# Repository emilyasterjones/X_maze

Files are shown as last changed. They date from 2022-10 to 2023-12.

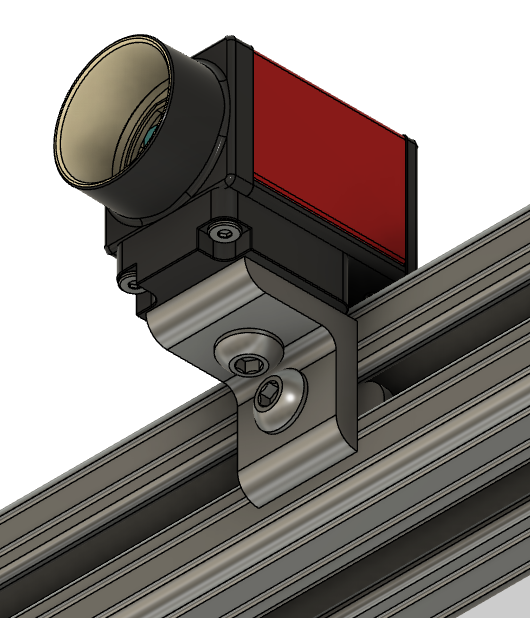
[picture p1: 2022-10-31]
Build/Camera_mount.png

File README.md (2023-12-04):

# X_maze
Build files and scripts for an automated delayed (non)match to direction task, with simultaneous video recording and TTL pulses to synchronize to additional data streams

This task is derived from the H maze, originally published in [(Seigle & Wilson, 2014)](https://elifesciences.org/articles/03061) with a detailed protocol published in [(Wirtshafter, Quan, & Wilson, 2021)](https://bio-protocol.org/e3947).

### GigE Allied Vision Camera Acquisition Instructions
1. Configure Ethernet Card
	1. Configure ethernet card according to [these settings](https://www.alliedvision.com/fileadmin/content/documents/products/cameras/various/installation-manual/GigE_Installation_Manual.pdf)
	1. [Turn off unnecessary protocols](https://www.mathworks.com/help/supportpkg/gigevisionhardware/ug/configure-gigabit-ethernet-network-adapter-on-windows.html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)
	1. [Set the camera's network to private](https://supportcenter.pleora.com/s/article/Correcting-Firewall-Issues-with-Third-Party-GigE-Vision-Devices-KBase)
1. Install OpenCV and Vimba SDK for Python
	1. `pip install opencv-python`
	1. Vimba => modify => select Vimba Python
	1. `pip install "C:/Program Files/Allied Vision/Vimba_X.X/VimbaPython/Source"` where x is whatever your version is
	
### FLIR Blackfly S USB3 Camera Acquisition Instructions
1. Install [SpinView](https://www.flir.com/products/spinnaker-sdk) to set camera settings and stream and record video. See camera_settings file for an example of streaming high resolution color video in dim lighting.
2. Read the [Blackfly S Manual](https://www.eureca.de/files/pdf/optoelectronics/flir/BFS-Installation-Guide.pdf).
3. To set up PySpinCapture to record using the GPU by installing the following:
* [Visual Studio (2022)](https://visualstudio.microsoft.com/)
* [CUDA Toolkit 12.2](https://developer.nvidia.com/cuda-downloads)
* [NVIDIA Video Codec SDK (12.1)](https://developer.nvidia.com/nvidia-video-codec-sdk/download)
* [Python (3.8)](https://www.python.org/downloads/)
* [Python Spinnaker SDK for your Python version](https://www.flir.com/support-center/iis/machine-vision/downloads/spinnaker-sdk-download/spinnaker-sdk--download-files/)
* [FFmpeg (6.0)](https://ffmpeg.org/download.html)
4. Set up Conda environment:
```
conda create -n flir python=3.8
pip install skikit-video
```

5. Update folders and constants in capture_video_FLIR.py, then run:
`python capture_video_FLIR.py name_of_output_video_file_stem` to capture video.

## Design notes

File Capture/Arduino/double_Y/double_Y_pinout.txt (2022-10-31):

Pin	Type	Loc
0	NA	NA
1	NA	NA
2	IR	TopLeft
3	IR	BottomLeft
4	IR	TopRight
5	Door	TopLeft
6	Door	BottomLeft
7	IR	BottomRight
8	Solenoid	TopLeft
9	Solenoid	BottomLeft
10	Door	TopRight
11	Door	BottomRight
12	Solenoid	TopRight
13	Solenoid	BottomRight
A0	TTL	NA
A1	NA	NA
A2	NA	NA
A3	NA	NA
A4	NA	NA
A5	NA	NA

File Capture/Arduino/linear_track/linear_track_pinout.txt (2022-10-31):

Pin	Type	Loc
0	NA	NA
1	NA	NA
2	IR	Left
3	IR	Right
4	NA	NA
5	NA	NA
6	NA	NA
7	NA	NA
8	Solenoid	Left
9	Solenoid	Right
10	NA	NA
11	NA	NA
12	NA	NA
13	NA	NA
A0	TTL	NA
A1	NA	NA
A2	NA	NA
A3	NA	NA
A4	NA	NA
A5	NA	NA

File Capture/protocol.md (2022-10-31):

## Overarching Protocol
### Housing
#### General
* Reverse light/dark cycle, ideally 1-2 weeks before pre-op training. 
* Add wheel to encourage running and wood block since chewing is reduced on food dep.

#### Food restriction
**Pre-op, on day....**
* 0. Remove hopper, change cage, add restriction card.
* 0-2. 1.5g/mouse plus a weigh boat with soy milk.
* 3+. Adjust by weight.

1 day before surgery, single house without wheel. Return to free feeding, staying with food on the floor. Add gel food & water (for easy access during recovery), sprinkles (to encourage foraging), and nestlet (for heat support).

**Post-op, on day....**
* 0-3. Ad lib food.
* 4-5. 2g/mouse plus soy milk.
* 6+. Adjust by weight. Note that mice remain underweight for some time postop, so don't go below their pre-op baseline (weight of implant = 4g ~= 15% of a 25g mouse's weight)

### Training order
**Pre-op, on day.....**
* 0. Set up cage and begin food restriction. Label tails with sharpies.
* 1 & 2. Open field (OF) for 30 minutes with running wheel and lots of toys. Handle mice.
* 3+. Linear track (LT) for 20-30 minutes. Start at 25uL reward, lowering gradually to 10uL over days so mice on average get <1.5mL during tracks runs so they don't get sated.
* n+. Once mice reach 2 trials/min for 2 days, X-maze double-forced for 20-30 minutes, with same reward progression. Continue until 4 trials/min for 2 days. Optional: switch to X-maze probe, continuing until 75% correct for 2 days. Can run 2 sessions per day to speed up learning if needed.

**Post-op, on day....**
* 1-3. Record 10-20 min in OF. 
* 4+. Record HC => LT => HC => OF, 20 minutes each, until 4 trial/min or 3 days, whichever comes last. Make each recording epoch a separate trigger on the SpikeGLX file. 10uL reward for all tracks.
* n+. Substitute LT for X-maze probe. Continue until until 75% correct or 10 days, then switch to X-maze reversal, also continuing until 75% correct or 10 days.

## Daily protocol
### Set up
#### Behavior
1. Fill syringe with milk. Release valve, let descend to poke, then close again.
1. Thread tubing into solenoid. Clean poke. Open syringe valve. Fill syringe to target volume.
1. Switch on track hardware.
1. Do a test run to make sure the hardware functions are nominal. Swap out any nonfunctional components.
1. Dim lights to 5 lux. Close curtains and door.
1. Open camera in Vimba to confirm network adapter is still running. Restart computer if it isn't.
1. Remove yesterday's SpikeGLX sessions from the local drive

### Recording
#### Between animals
1. **PuTTy**: load "Arduino" settings. Under "Logging", enter the file name & location.
1. **Spyder**: set filename.
1. Wipe down the track and wheel. Reload the syringes to 5mL.
1. Weigh the next animal.

#### SpikeGLX
1. Plug in mouse: headfix with 1 screw, remove tape, release flex cable from slot, put headstage holder into slot, re-attach tape, plug flex cable into headstage, turn on LEDs.
1. Start acquisition and examine for abnormalities. Set filename.
1. Put mouse on the track next to and facing first poke.
1. Press "Enable Recording".

#### Behavior
1. Press "Open" to restart the Arduino and save all the output to the designated file. _Note: you can't have more than 1 program using the same port at once, so you can't have the Arduino IDE and PuTTy open at the same time._
1. Confirm TTL pulses appear on SpikeGLX.

#### Camera
1. Start the camera.
1. Confirm TTL pulses appear on SpikeGLX.

#### End Epoch
1. Stop video, then behavior, then recording.

#### End Session
1. Stop acquisition.
1. Put mouse back on the ball and unplug. Retape the flex slot.
1. Untwist the data cable.

### Clean up
1. Feed the mice.
1. Switch off power to track hardware. _Note: leaving solenoids plugged in for too long can cause them to fry._
1. Release tubing from solenoid. Drain milk, then rinse with water. Pump air through with plunger to dry.
1. Wipe everything again.
1. _Once a week_: Fill with ethanol/bleach and close valve. Let sit overnight.

### Troubleshooting
* **Arduino**: Check that power strip and switches are turned on and syringe valves are open. Confirm you are on the correct port and that you switched all the wiring and tubing between tasks correctly. Check that all wiring is securely connected. Try adding debug statements to the code in Arduino IDE, uploading it, and testing the task manually.
* **SpikeGLX**: If probe fails, clean the gold pins with IPA and try again.

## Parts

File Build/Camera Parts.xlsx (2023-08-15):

Build | Part | Short Name | Vendor | Cat # | Quantity | Price | Subtotal
Allied Vision - Mako G (capture_video.py) | AVT-GK-158C-POE Camera, GigE PoE, Sony IMX273; 1/2.9" CMOS; C-Mount; color; 1456x1088; 75.3fps; 12-bit ADC; IRC filter | GigE C-mount 75fps camera | 1st Vision | AVT-GK-158C-POE | 1 | 520 | 520
 | Cable, Hirose-8-pin to flying leads, 10m | Hirose 8-pin to bare ends cable | 1st Vision | CB-HIR8-I/O-10M | 1 | 150 | 150
 | Cable, CAT6 ethernet RJ45, screw locks, industrial grade, 10m | Ethernet cable | 1st Vision | CB-ALY-G-C6-SL-10M | 1 | 95 | 95
 | Lens, Kowa 6mm C Mount 2/3” C-mount | C-mount 6mm lens | 1st Vision | KOW-LM6JC | 1 | 130 | 130
 | Vostro 3681 Small Desktop | Computer | Dell | cav3681w10ps5095 | 1 | 749 | 749
 | Gigabit CT PCIe Desktop Adapter | Ethernet adapter | Dell | a2290104 | 1 | 42.99 | 42.99
 | 5.9" (149.86mm) BNC, Female Socket (Jack) To Wire Lead Test Lead 500VAC | BNC to bare ends | Digikey | 501-1030-ND | 1 | 10.29 | 10.29
 | AC to DC Power Supply Wall Adapter Transformer Single Output 12 Volt 1 Amp 12 Watt | Low noise power supply | Jameco | 170245 | 1 | 14.95 | 14.95
FLIR - Blackfly (pySpin) | Blackfly USB3 23S3C-C 2.3MP, Sony IMX392, 1/2.3" CMOS, C-mount, color, 1920x1200, 163fps, 12-bit ADC | USB C-mount 163fps camera | FLIR | BFS-U3-23S3C-C | 1 | 421 | 421
 | 6 pins, 4.5m GPIO Cable, Hirose HR10 Circular Connector | Hirose 6-pin to bare ends cable | FLIR | ACC-01-3010 | 1 | 43.9 | 43.9
 | USB 3.1, 5m, Type-A to Micro-B (Locking) Cable | USB cable | FLIR | ACC-01-2301 | 1 | 37.5 | 37.5
 | Fujinon DF6HA-1B, 6mm, 1/2", C mount Lens | C-mount 6mm lens | FLIR | LENS-15F3-60C | 1 | 238 | 238
 | 26.9mm by 17.9mm, 1/4"-20 Tripod Adapter | Tripod adapter | FLIR | ACC-01-0003 | 1 | 11.8 | 11.8
 | Alienware Aurora R16: i7-13700F, NVIDIA GeForce RTX 4070, 32GB DDR5 5600 MT/s, 1TB SSD | Computer | Dell |  | 1 | 1899 | 1899
 | 5.9" (149.86mm) BNC, Female Socket (Jack) To Wire Lead Test Lead 500VAC | BNC to bare ends | Digikey | 501-1030-ND | 1 | 10.29 | 10.29

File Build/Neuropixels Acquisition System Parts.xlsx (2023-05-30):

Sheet: Parts List
Part | Vendor | Catalog # | Cost in Euros | Cost in Dollars | Notes
Headstage | IMEC | HS_1000 | 250 | 300 | Buy backups in case of failure
PXIe Acquisition Module | IMEC | PXIe_1000 | 2400 | 2880 | IMEC PXIe module
Interface Cable | IMEC | CBL_1000 | 175 | 210 | Buy backups in case of failure
Coaxial Cable, SMA Male to BNC Male | Thorlabs | CA2848 |  | 19.37 | connects IMEC module to the BNC board
NI PXIe-1071, 4-Slot 3U PXI Express Chassis | National Instruments | 781368-01 |  | 1274 | Chassis
APS-4100 Auxiliary Power Source for NI DC Power Supplies | National Instruments | 779671-01 |  | 276 | Chassis power (optional)
Power Cord, AC, U.S., 120 VAC, 2.3 meters | National Instruments | 763000-01 |  | 13 | Chassis power
PXIe-6341, X Series DAQ | National Instruments | 781052-01 |  | 1404 | NI DAQ PXIe module; 24 DIO but only 8 at 1MHz
BNC-2110 Noise Rejecting, Shielded BNC Connector Block | National Instruments | 777643-01 |  | 446 | Sync block
SHC68-68-EPM Shielded Cable, 68 D-Typeto 68 VHDCI Offset, 0.5m | National Instruments | 192061-0R5 |  | 132 | Connects DAQ to sync block
NI PCIe-8381, x8 Gen2 MXI-Express for PXI Express Interface | National Instruments | 782361-01 |  | 1552 | Remote control PXIe module
NI PXIe-8381, x8 Gen2 MXI-Express for PXI Express Interface | National Instruments | 782362-01 |  | 1552 | Remote control PC module
MXI-Express Cable, Gen 2 x8, Copper, 5m | National Instruments | 782317-05 |  | 428 | Cable between RC modules
BNC Terminator, 10-Pack RFAdapter 50 Ohm RF Coax Adapter Connector Coaxial Cable End | Amazon | B07WPR8L6B |  | 9.99 | Prevents TTLs from carrying over into empty channels
Tripp Lite 12-outlet surge protector | Home Depot | TLP1208TELTV |  | 43.59 | Prevent hard drive failure due to power surge or outage
PC (see next tab) |  |  |  | 4000
Monitor |  |  |  | 250
Alternatives:
NI PCIe-8381, NI-PXIe-8381, MXI-Express Cable Bundle | NI | 782522-01 |  | 2975 | Bundle for the PCIe/PXIe and cable
PXIe -6363, X Series | NI | 781056-01 |  | 2691 | alternative to the 6341. NI DAQ PXIe module; 48 DIO, 32 at 1MHz
SCB-68A | NI | 782536-01 |  | 385 | alternative to the bnc board.
MXI-Express Cable, Gen 2 x8, Copper, 3m | National Instruments | 782317-03 |  | 286 | alternative/shorter mxi cable. this is the one included in the bundle above
Probes:
NPX 1.0 Probes w Cap (Box 5) | IMEC | PRB_1_4_0480_1_C | 6000 | 7200
Dummy NPX 1.0 Probes w Cap (Box 6) | IMEC | DPRB_1_4_0480_1_C | 900 | 1080

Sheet: Computer Specs
Minimum for Neuropixels: PCle chassis, minimum processing power, SSD, 1TB storage
Part | Type | Notes
Chassis | Precision 5820 Tower XCTO Base, 950W, PCle FlexBay RTX Chassis | PCle chassis required
Processor | Intel Xeon W-2133, DDR4-2666 | Intel processor required
Video card | Nvidea Quadro RTX4000, 8GB, 3DP, VirtualLink (XX20T)
Memory | 64GB DDR4 2666MHz | Required for processor
Boot drive | Intel NVMe PCle SSD
Storage drive controllers | RST-e with 1-2 Front FlexBay NVMe PCle Drives
Storage drive | M.2 1TB PCle NVMe Class 40 SSD | SpikeGLX records 75GB/probe/hour, so adjust according to your expected daily recording output

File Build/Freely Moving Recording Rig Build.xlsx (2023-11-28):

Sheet: Tap Plastics (enclosures)
Enclosure | Part | Quantity | Material | Height (in) | Width (in)
Rest Box | Floor | 1 | 1/8" P95 matte black acrylic | 6 | 6
Rest Box | Walls | 4 | 1/8" P95 matte black acrylic | 12 | 5 & 7/8
75cm OF | Floor | 1 | 1/4" P95 matte black acrylic | 30 | 30
75cm OF | Walls | 4 | 1/4" P95 matte black acrylic | 12 | 29 & 7/8
1.5m LT | Floor | 1 | 1/4" P95 matte black acrylic | 60 | 4
1.5m LT | Side Walls | 2 | 1/4" P95 matte black acrylic | 8 | 60
DY | Arm Walls | 8 | 1/4" P95 matte black acrylic | 8 | 20
DY | Hall Walls | 2 | 1/4" P95 matte black acrylic | 8 | 8 & 5/8
DY | Doors | 4 | 1/8" P95 matte black acrylic | 7 3/4 | 3 & 1/2
DY | Rudders | 8 | 1/2" P95 matte black acrylic | 2021-03-08 | 2
All |  | 1 | Caulking Gun
All |  | 1 | Sil-Pruf 10.1Oz Black
All |  | 1 | Weld-On 3 Cement (4 oz.)
All |  | 1 | Small BD-25/2 Hypo Applicator
All |  | 1 | Polypropylene Funnels
 |  |  | 1.4

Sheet: 8020.net (frame)
Part | Length (in) | Quantity | Cat # | Price | Subtotal
1.50” X 1.50” Ultra-LiteT-Slotted Profile - Four Open T-Slots | 65 | 8 | 1515-UL | 30.06 | 240.48
1.50” X 1.50” Ultra-LiteT-Slotted Profile - Four Open T-Slots | 90 | 4 | 1515-UL | 40.81 | 163.24
1.50” X 1.50” Ultra-LiteT-Slotted Profile - Four Open T-Slots | 15.25 | 12 | 1515-UL | 8.67 | 104.04
1.50” X 1.50” Ultra-LiteT-Slotted Profile - Four Open T-Slots | 43 | 14 | 1515-UL | 20.6 | 288.4
1.50” X 1.50” Ultra-LiteT-Slotted Profile - Four Open T-Slots | 8 | 3 | 1515-UL | 5.55 | 16.65

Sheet: McMaster (frame accessories &
Part | Short Name | Cat # | Quantity | Price | Subtotal | For
T-Slotted Framing, Snap Close Cable Holder with 1 Opening for 1 1/2" High Rail | Cable Holder | 47065T388 | 12 | 3.24 | 38.88 | Cable organizing
T-Slotted Framing, Grounding Terminal with Fasteners | Ground terminal | 5537T491 | 1 | 3.75 | 3.75 | Grounding the frame
T-Slotted Framing, Antislip Leveling Mount for 1-1/2" High Single Rail | Leveling foot | 47065T342 | 4 | 8.2 | 32.8 | Leveling the frame
Silver Corner Bracket, 1.5" Long for 1.5" High Rail T-Slotted Framing | Single L-bracket | 47065T845 | 95 | 6.24 | 592.8 | Attaching most frame pieces
Silver Corner Bracket, 3" Long for 1-1/2" High Rail T-Slotted Framing | Double L-bracket | 47065T241 | 26 | 6.77 | 176.02 | Connecting larger joints on frame
Hanging Pulley for Rope-for Horizontal Pulling; Single-Groove, Rigid Eye, for 5/16" Diameter Rope | Acetyl pulley | 3221T75 | 2 | 18.73 | 37.46 | Pulley
Black-Oxide Alloy Steel Socket Head Screw; 10-24 Thread Size, 1-1/2" Long, Fully Threaded (pack of 25) | 10-24 screws | 90044A115 | 1 | 9.62 | 9.62 | Pulley
Steel Round-Base Weld Nut; Zinc-Plated, 10-24 Thread Size, 23/32" Base Diameter (pack of 25) | Wide-bottom nuts | 90596A220 | 1 | 5.92 | 5.92 | Pulley
Clear Nylon Line, 0.022" Diameter | Pulley line | 944sT3 | 1 | 11.86 | 11.86 | Pulley
Tray for 1-1/2", 30 mm and 40 mm High Rail, Black, 4-5/16" Wide | T-slot tray | 5537T683 | 2 | 8.78 | 17.56 | Storage
Drop-in Nut with Spring Loaded Ball, 5/16"-18 Thread Size | Drop-in T nut | 47065T327 | 120 | 1.31 | 157.2 | Attaching pieces once frame is assembled
Duct Tape, Black, 1-1/2" Wide, 180 Feet Long | Matte black duct tape | 76135A62 | 1 | 10.34 | 10.34 | Securing enclosure joints
Drop-in Nut with Spring Loaded Ball, 1/4"-20 Thread Size | Drop-in T nut for headbar holder | 47065T326 | 6 | 1.51 | 9.06 | Mounting Thorlabs pieces to 80/20

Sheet: Home Depot (storage)
Part | Cat # | Quantity | Price | Subtotal
White 5-Tier Metal Wire Shelving Unit (18 in. W x 72 in. H x 24 in. D) | 309372407 | 1 | 80.87 | 80.87
18-Qt. Latch Storage Box | 204724980 | 2 | 8.98 | 17.96
30-Qt. Latch Storage Box | 204724998 | 2 | 12.98 | 25.96
Akro-Mils Small parts organizer cabinet

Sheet: Pipe & Drape (curtains)
Item # | Item | Quantity | Each | Subtotal
B505 | OPTIONAL: 16" x 14" Slip Fit Base with Pin - 10 lbs; CHOOSE BASE PIN SIZE: 6'' Tall for 1.5'' Diameter Upright (+$2.00) | 3 | 23.56 | 70.68
B102BK | OPTIONAL: 8 Foot Tall Fixed Black Upright - 1.5'' Diameter | 3 | 42.7 | 128.1
TB-P-BK | Premier Tieback Band, Black | 3 | 3.58 | 10.74
B401 | 4 - 7 Foot Adjustable Width Support Rod | 2 | 22.03 | 44.06
D703-BK | 8 Foot Tall Premier Drape, Black (Durably Flame Retardant) | 3 | 22.61 | 67.83

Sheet: Arduino
Part | Vendor | Cat # | Quantity | Price | Purpose
Arduino Uno - R3 | Sparkfun | 11021 | 2 | 22.95 | Operate linear track and H-maze (1 each)
BNC to wire leads | Digi-key | 501-1030-ND | 1 | 11.19 | Send TTL pulses from Arduino to BNC breakout board to synchronize with neural data
Arduino screw terminal block breakout module | Amazon | B07HF2DD7T | 1 | 20.99 | Secure jumper cables so they can't fall out of the Arduino
USB A to USB B 15' cable | Digi-key | 2671-USBG-AB15CC-ND | 1 | 4.28 | Connect Arduino to computer

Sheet: Wiring Nosepoke, Solenoid, and
Component | Part | Vendor | Cat # | Quantity | Price | Purpose
All | Maxwel Manufacturing 2:1 Heatshrink Tubing | Amazon | B0722HN8SW | 1 | 11.99 | Cover wire joints after soldering
All | Resistor kit | Sparkfun | 10969 | 1 | 7.95 | Camera and poke wiring
All | Jumper wires M/F (pack of 20) | Sparkfun | 12794 | 10 | 1.95 | Connecting components and Arduino
All | 24AWG green & white twisted wire | Jameco | 105807 | 1 | 89.95 | Wires spanning distances between components and power/Arduino
All | Consolidated 22AWG red wire (25 ft) | Parts Express | 101-757 | 1 | 3.79
All | Consolidated 22AWG black wire (25 ft) | Parts Express | 101-755 | 1 | 3.79
All | TE Connectivity Socket | Allied Electronics | 66505-9 | 100 | 0.15 | Connecting components
All | TE Connectivity Pin | Allied Electronics | 66507-9 | 100 | 0.23 | Connecting components
All | 2.5mm inline switch | MPJA | 34248 SW | 3 | 2.95 | Power doors and pokes
All | 2.1mm inline switch | Sparkfun | 11705 | 2 | 2.5 | Power solenoids (same as one used for camera)
All | 2.5mm power barrel | Digikey | CP-037BH-ND | 3 | 0.73 | Power doors and pokes
All | 2.1 power barrel | Digikey | CP-037A-ND | 2 | 0.69 | Power solenoids (same as one used for camera)
All | AC to DC 5 Volt 1 Amp 5 Watt power supply | Jameco | 168605 | 3 | 12.95 | Power doors and pokes
All | AC to DC 12 Volt 1 Amp 12 Watt power supply | Jameco | 170245 | 2 | 14.95 | Power solenoids (same as one used for camera)
Nosepoke | Stainless steel hypodermic tubing, 304 steel, 19rw gauge (0.0425" OD, 0.033" ID) | Microgroup | 304H19RW | 1ft | 8.29 | Spout for nosepoke
Nosepoke | 1/2" 4/40 screws (pack of 100) | McMaster | 91802A110 | 1 | 4.17 | Mount pokes to walls
Nosepoke | Infrared emitter | Sparkfun | 18772 | 6 | 0.95 | Detect pokes
Nosepoke | Infrared detector | Sparkfun | 19018 | 6 | 0.95 | Detect pokes
Solenoid | Solenoids: 1 tube, normally closed, 12V, takes 1/16" x 1/8" tubing | NResearch | 225P011-21 | 6 | 64.67 | Dispense reward (NOTE: buy spares of this part, as they can fry easily)
Solenoid | MOSFET power control unit | Sparkfun | 12959 | 6 | 5.25 | Control solenoids
Solenoid | Black cable ties (pack of 100) | Home Depot | 203531910 | 1 | 9.87 | Mount solenoid to poke
Servo motor | Futaba S3003 Servo | Amazon | B0015H2V72 | 4 | 13.95 | Motor for doors
Servo motor | Futaba alloy heavy duty servo arm 37mm x M2 | HobbyKing | 17000077 | 4 | 2.31 | Arm for doors
Servo motor | White plastic binding head slotted screws (pack of 100) | McMaster | 94690A714 | 1 | 8.31 | Mount motor beneath floor
Servo motor | Loctite super glue | Home Depot | 100371839 | 1 | 3.68 | Connect doors to servo motor arms

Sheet: Reward delivery
Part | Vendor | Cat # | Quantity | Price | Purpose
Chocolate soy milk singles | Amazon | B00IGUDNEG | 12 | 13.39 | Reward (shelf-stable until opened, one single will get used up before it goes bad in the fridge)
Super-soft latex rubber tubing (1/16" inside, 1/8" outside) | Mcmaster | 5234K93 | 50ft | 59.5 | Carry liquid reward from syringe to nosepoke
10mL luer lock syringes (pack of 100) | Fisher Scientific | 14-823-2A | 1 | 26.65 | Hold reward
1" velcro tape (10ft) | Home Depot | 205185844 | 1 | 19.98 | Mount syringes to 80/20
Stopcocks w/ luer connections, 4-way, male lock (10 pack) | Cole Parmer | EW-30600-04 | 1 | 40.75
Female luer to 1/16" barb (pack of 25) | Cole Parmer | EW-45501-01 | 1 | 16.9
Male luer lock plug | Cole Parmer | EW-30800-30 | 1 | 12.7
Tube fitting, luer M to luer F (pack of 25) | Warner instruments | 64-1577 | 1 | Unknown
Polyethylene wash bottles | Fisher scientific | S29369 | 3 | 11.4 | Add reward, wash water, or wash ethanol to syringes (exactly fits 1 soy milk single)
Smart weight 500g scale | Amazon | B00ME8VI34 | 1 | 13.99 | Weigh mice
Plastic food tubs |  |  |  |  | Store mouse chow
Scissors |  |  |  |  | Cut mouse chow into smaller pieces
6-well plates |  |  |  |  | Store pre-weighed mouse chow

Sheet: Thorlabs (headfixation)
Part | Cat # | Quantity | Price | Subtotal | For
1.5" mounting post | P14 | 1 | $97.39 | $97.39 | Headfork post
1.5" post base | PB1 | 1 | $26.18 | $26.18 | Attach headfork post to 8020
1.5" mounting post bracket | C1515 | 1 | $107.13 | $107.13 | Attach headfork to post
6"-long 0.5" diam post | TR6 | 2 | $7.33 | $14.66 | Wheel mount
3"-long 0.5" diam post holder | PH3 | 2 | $8.52 | $17.04 | Wheel mount base
pedestal adapter for 0.5" diam post holder | BE1 | 2 | $10.06 | $20.12 | Attach wheel mount base to holder
Clamping Fork | CF175C | 2 | $12.77 | $25.54 | Attach holder to 8020
Right-Angle Clamp for Ø1/2" Posts to 6mm posts, 3/16" Hex | RA90TR | 2 | 16.56 | 33.12 | Attach wheel axle to mount
Mounting Base, 1" x 4.5" x 3/8" | BA1L | 1 | 12.93 | 12.93 | Attach headfork to bracket
1/4"-20 Cap Screw and Hardware Kit* | HW-KIT2 | 1 | 132.93 | 132.93 | Attach headfork to post bracket
* this build uses the following components, which can also be bought separately instead of as a kit: 1/4"-20 screws of 1/2" and 1" length (2 each), 2 1/4" washers, 2 1/4" nuts

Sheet: Other vendors
Part | Vendor | Cat # | Quantity | Price | Purpose
Licron Crystal ESD Safe Coating | Digikey | 1873-1756-8S-ND | 1 | 44.92 | Anti-static coating for enclosures
Machine Screw: M3, 8mm Length, Phillips (25-pack) | Pololu | 1076 | 1 | 1.29 | Screws to attach camera to mount
Devcon 31345 2 Ton Clear Epoxy, 25 ml | Amazon | B0006O8QQ0 | 1 | 6.9 | Epoxy for acrylic joints and joining nosepoke piece
Black-oxide alloy steel socket head screw 0-80 thread size, 1/8" long (box of 50) | McMaster | 91251A052 | 1 | 3.13 | Headbar screws (magnetic)
Allen SAE magnetic ball-plus hex key set | Amazon | B00514UAGC | 1 | 22.75 | Affixing headbar screws (magnetic)
Reusable Cable Ties | Amazon | B083FKB7BL | 1 | 9.99 | Attaching cables to 80/20 frame
InnoDome (case of 300) | Bio-Serv | S3174 | 1 | 225 | Encourage running
InnoWheel (case of 150) | Bio-Serv | S3175 | 1 | 160 | Encourage running
Scotch extreme fasteners (10ft) | Amazon | B00IGIUP9O | 1 | 22.68 | Mount local cues and objects
15mL conical tube |  |  | 1 |  | Pulley counterweight
Foam roller | Amazon | B00X87C898 | 1 | 23.95 | Wheel for headfixation
Rustoleum flat black spray paint | Amazon | B002BWOS7Q | 1 | 4.49 | Paint wheel black
20cm long, 6mm diameter metal rod |  |  |  |  | Wheel spoke

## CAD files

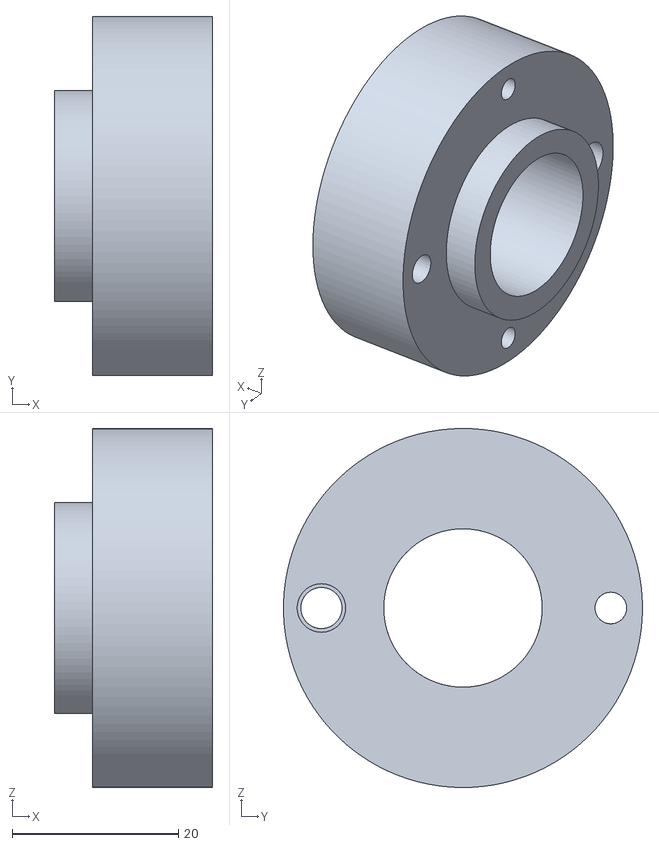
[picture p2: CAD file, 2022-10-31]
Build/Kreitzer_Lab_Face_Mount_v0.stl
19.0 x 43.2 x 43.2

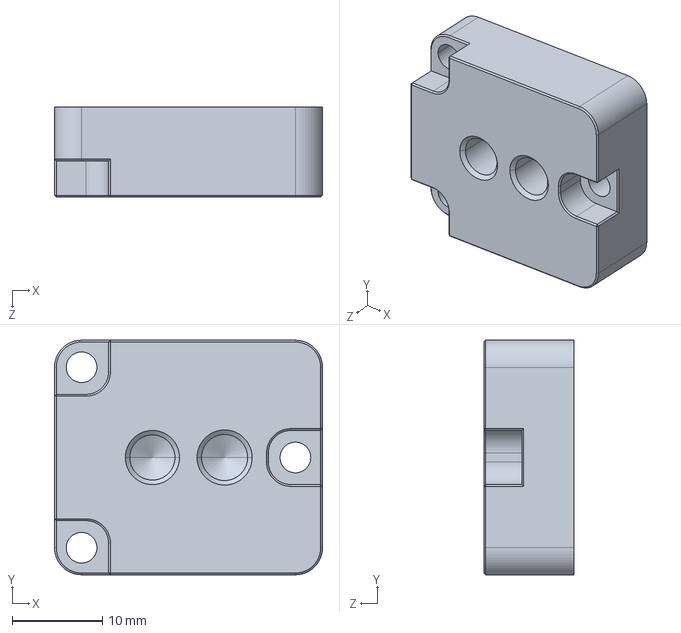
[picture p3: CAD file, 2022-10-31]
Build/Mako-G_Tripod-Adapter.STEP
29.7 x 26.0 x 10.0 mm

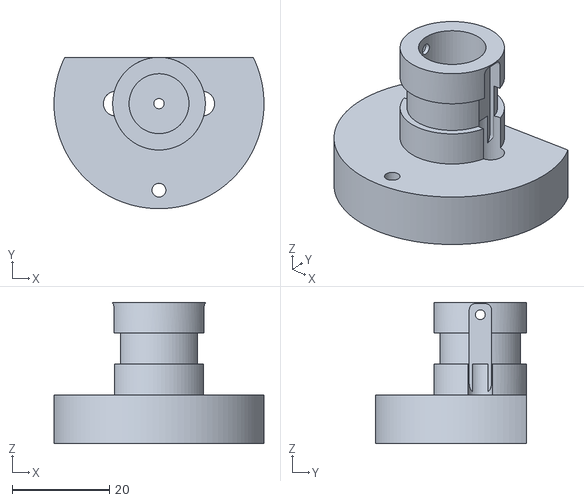
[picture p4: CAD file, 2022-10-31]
Build/Kreitzer_lab_Electronics_Mount_v0.stl
43.2 x 31.1 x 29.0

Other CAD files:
Build/Camera_mount.f3d
Build/Kreitzer_Lab_Electronics_Mount_v0.f3d
Build/Kreitzer_Lab_Face_Mount_v0.f3d

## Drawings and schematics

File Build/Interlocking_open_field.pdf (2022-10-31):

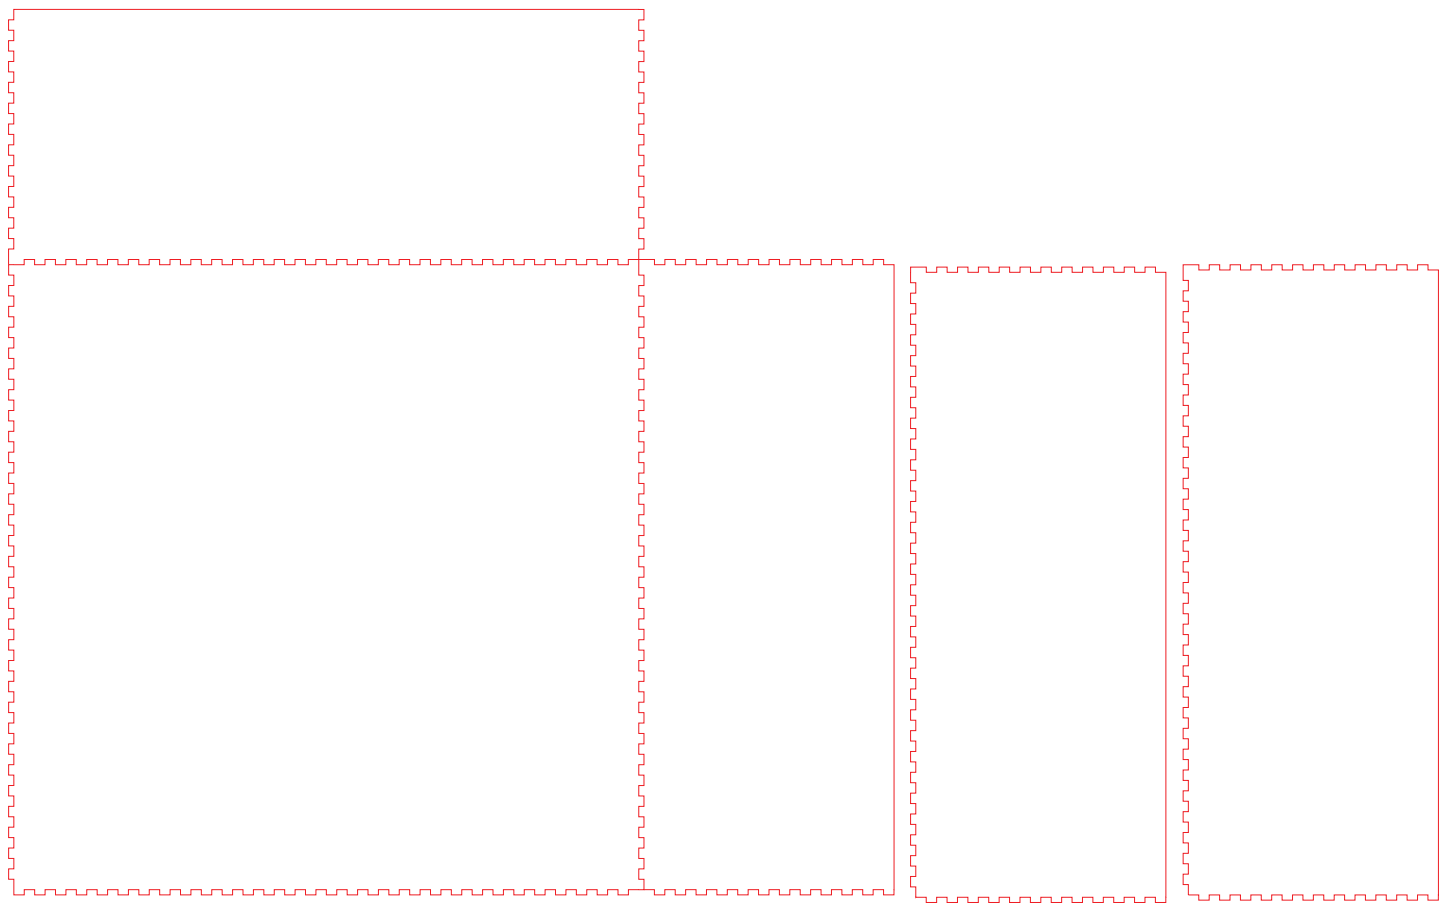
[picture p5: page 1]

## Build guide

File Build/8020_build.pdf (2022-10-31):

Pos | Article-No | Description | Units | Qty | Each $ | Price $
1 | 2.11.015015.43LP-AL0A00/90.000 | Profile 1.5"x1.5", 4E, light, plain Depth of thread, left: 16.0 mm | IN | 4 | 57.88 | 231.53
2 | 2.11.015015.43LP-AA4AA4/15.000 | Profile 1.5"x1.5", 4E, light, plain | IN | 6 | 14.81 | 88.88
3 | 2.11.015015.43LP-AA4AA4/15.252 | Profile 1.5"x1.5", 4E, light, plain | IN | 6 | 14.96 | 89.76
4 | 2.11.015015.43LP-AA4AA4/65.000 | Profile 1.5"x1.5", 4E, light, plain | IN | 8 | 44.19 | 353.54
5 | 2.11.015015.43LP-AA4AA4/43.000 | Profile 1.5"x1.5", 4E, light, plain | IN | 10 | 31.27 | 312.66
6 | 1.44.203008 | Manual levelling foot 30 | EA | 4 | 7.18 | 28.72
7 | 2.21.15E0 | Connector, universal | EA | 60 | 3.37 | 202.20
8 | 1.35.11208 | Threaded insert M12/M8 | EA | 4 | 1.38 | 5.52
Total Weight: | 69.75 kg (153.78 lbs) | Total (USD): | $ 1312.81
* The price indicated above, does not include assembly, packaging, taxes and transport.
Version : 7.250 | Page 1
Design Title | : 8020_build.scene
Customer Name | :
Date | : 2021-06-30

## Construction documentation

# Bill of materials (Number of kits: 1)

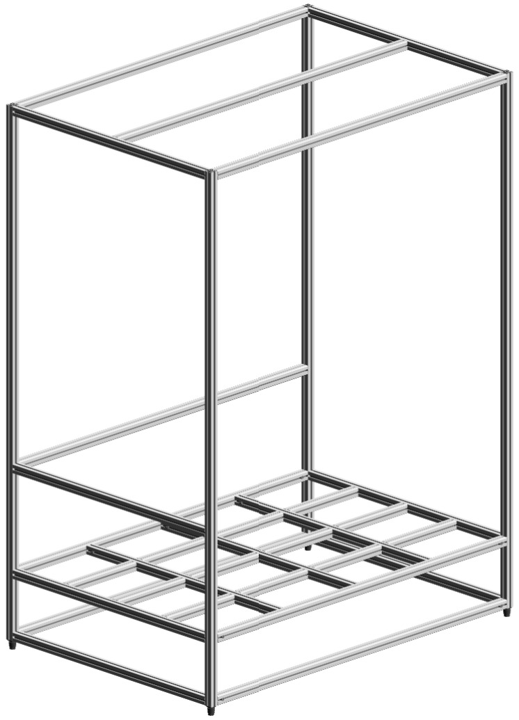
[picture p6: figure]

Version : 7.250 | Page 2

# Isometric view

### Some accessories may not be shown

# Exploded view "Front" (isometric)

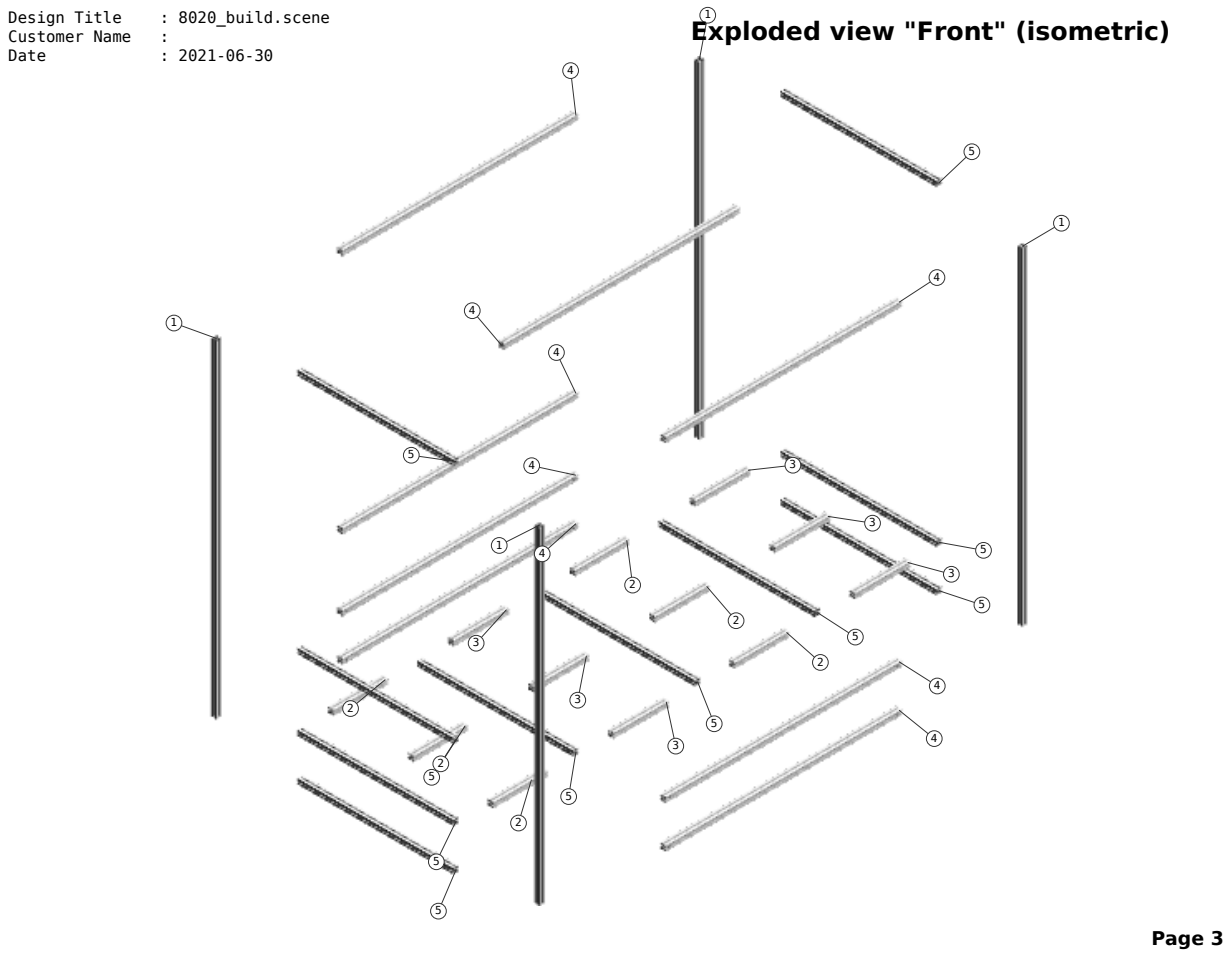
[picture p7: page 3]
Page 3

# Exploded view "Back"

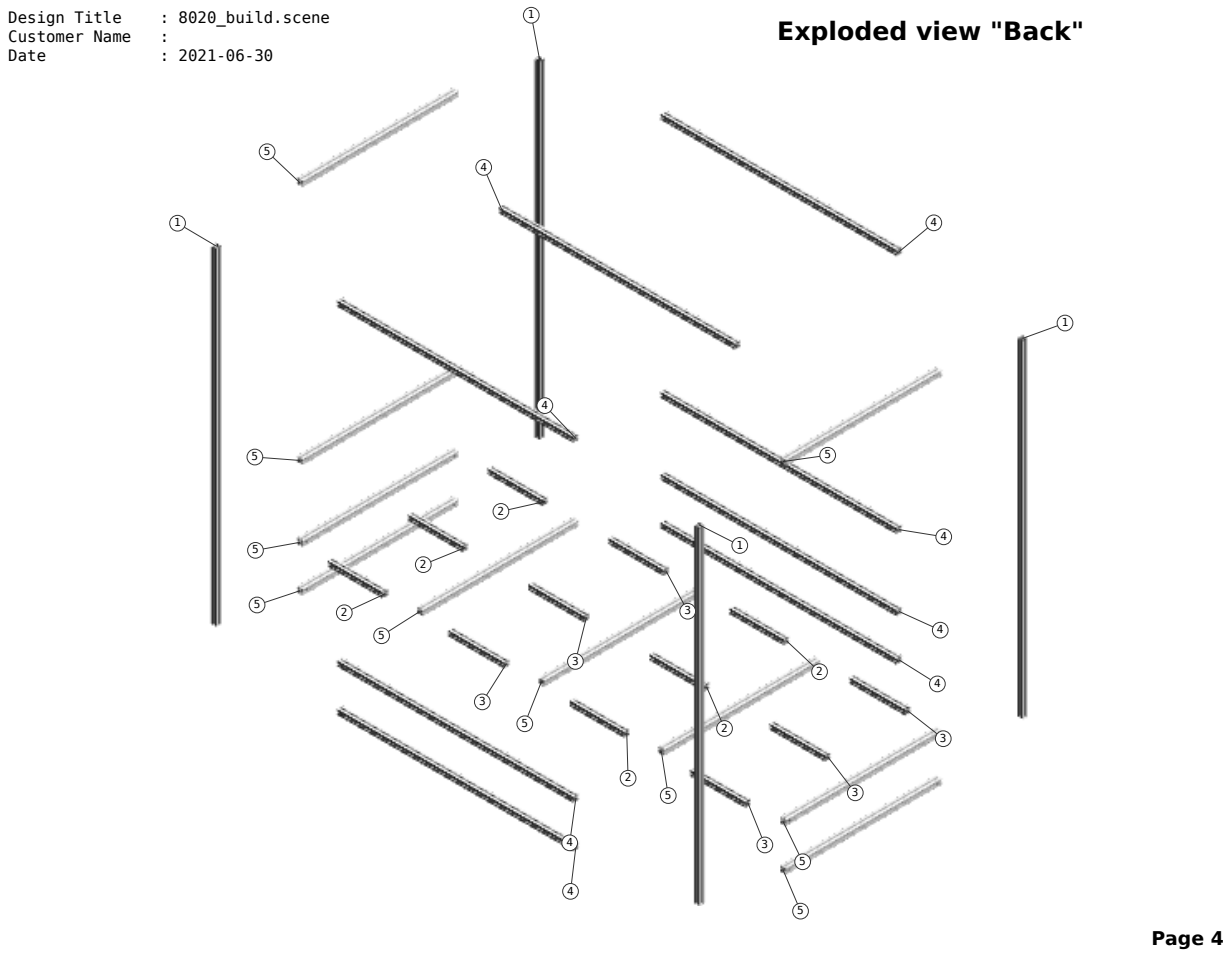
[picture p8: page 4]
Page 4

Pos | Article-No | Description | Related parts | Qty
2 | 2.11.015015.43LP-AA4AA4/15.000 | Profile 1.5"x1.5", 4E, light, plain
| | | 2.21.15E0, Connector, universal | 12
3 | 2.11.015015.43LP-AA4AA4/15.252 | Profile 1.5"x1.5", 4E, light, plain
| | | 2.21.15E0, Connector, universal | 12
4 | 2.11.015015.43LP-AA4AA4/65.000 | Profile 1.5"x1.5", 4E, light, plain
| | | 2.21.15E0, Connector, universal | 16
5 | 2.11.015015.43LP-AA4AA4/43.000 | Profile 1.5"x1.5", 4E, light, plain
| | | 2.21.15E0, Connector, universal | 20
6 | 1.44.203008 | Manual levelling foot 30
| | | 1.35.11208, Threaded insert M12/M8 | 4
Version : 7.250 | Page 5

# Assembly List

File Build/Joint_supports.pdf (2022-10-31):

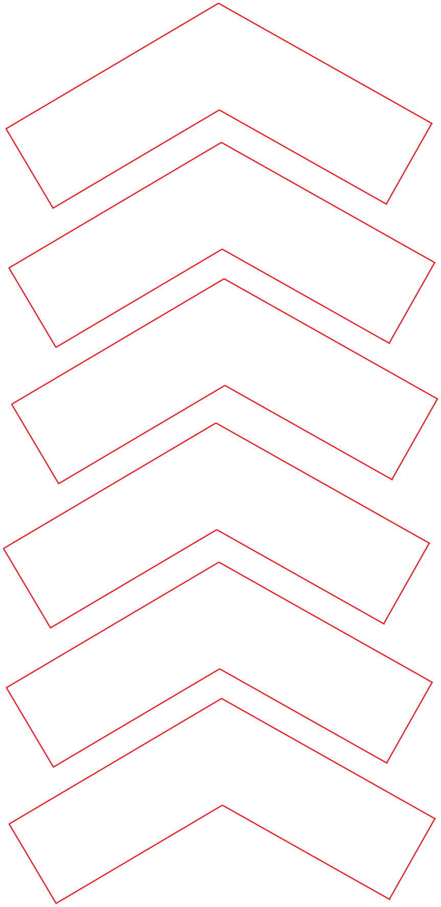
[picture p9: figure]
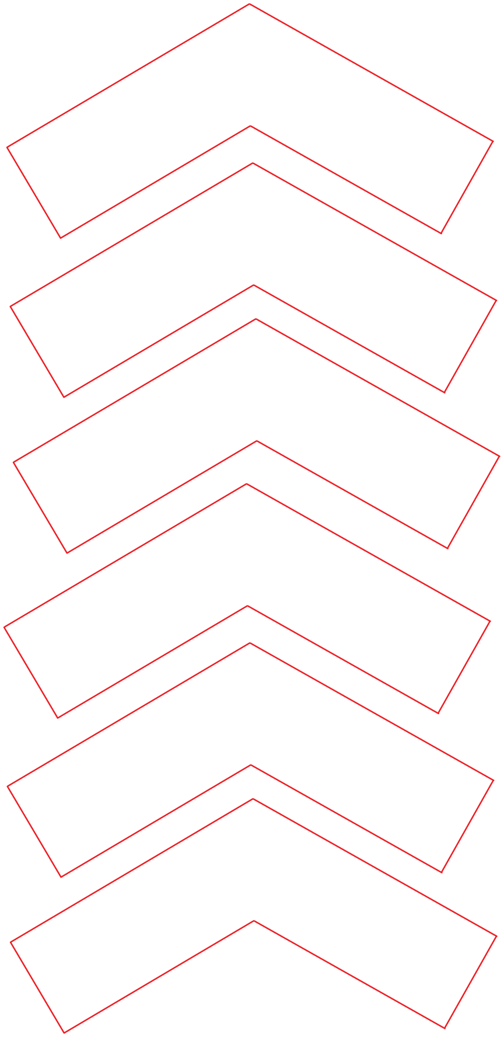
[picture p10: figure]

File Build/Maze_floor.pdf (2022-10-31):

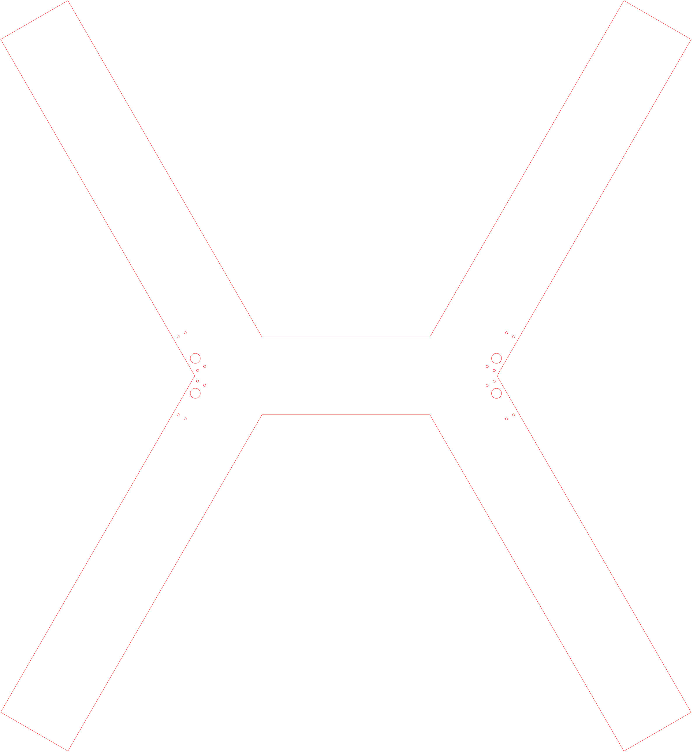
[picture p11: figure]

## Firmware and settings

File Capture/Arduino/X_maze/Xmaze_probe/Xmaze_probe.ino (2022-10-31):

/*
 * X-maze, probe
 * Mouse starts on the left and goes to the right, has to take either the bottom 
 * or the top trajectory.
 * Ports are TL (top left), BL, TR, BR.
 * 
 * init new session: open all doors, randomly close TL or BL door 
 * (then experimenter puts mouse in front of port with open door, then starts a 
 * session with the variable of which door was open)
 * 
 * loop: for each trial, wait for mouse poke at port behind open door => reward 
 * => wait for mouse poke at R port => if matches top/bottom of L port, 
 * reward + close open door => randomly open new or old door
 * 
 * output:
 * trial: counting up from 1
 * time: ms since script began
 * trajctory: 0=top, 1=bottom
 * initialized: 0=poking at left (start trial), 1=poking at right (end trial)
 * sucess: 0 or 1 (meaningless if initialized=0)
 */
#include <Servo.h>

// Input & output pins
const int n_pokes = 4;
//order: TL (top left), BL, TR, BR
const int IR_PINS[n_pokes] = {2,3,4,7};
const int SOLENOID_PINS[n_pokes] = {8,9,12,13};
const int SERVO_PINS[n_pokes] = {5,6,10,11};
const int TTL_PINS = A0;
Servo doors[n_pokes];

// State variables
int CORRECT_ARM; //0 for top, 1 for bottom
int TRIAL = 1;
int TRIAL_INITIATED = 0;
float PER_CORRECT = 0;
int TRIAL_TYPE_COUNT[4] = {0,0,0,0}; //TL->TR, TL->BR, BL->BR, BL->TR

// Other constants
const int REW_VOL = 10; //reward, in uL
const int MS_PER_UL[n_pokes] = {33/2, 26/2, 38*2, 18*2}; //microseconds to release 1uL of soy milk
const int OPEN_SOLENOID = 1;
const int CLOSE_SOLENOID = 0;
const int OPEN_DOOR[n_pokes] = {90,0,0,90};
const int CLOSE_DOOR[n_pokes] = {0,90,90,0};
const int START_TTL = 1;
const int END_TTL = 0;

void setup() {
  // initialize the data stream
  Serial.begin(9600); //or 115200

  // set pin modes as input or output
  for (int poke=0; poke<n_pokes; poke++){
    pinMode(IR_PINS[poke],INPUT);

    //close all solenoids
    pinMode(SOLENOID_PINS[poke],OUTPUT);
    digitalWrite(SOLENOID_PINS[poke],CLOSE_SOLENOID);

    //open all doors
    doors[poke].attach(SERVO_PINS[poke]); //servo version of pinMode(SERVO_PINS[poke],OUTPUT);
    doors[poke].write(OPEN_DOOR[poke]); //servo version of digitalWrite(SERVO_PINS[poke],OPEN_DOOR);
  }

  CORRECT_ARM = 1;
  //randomly close top or bottom left door (incorrect arm)
  //randomSeed(analogRead(1)); //randomize the random generator
  //CORRECT_ARM = random(2);
  doors[!CORRECT_ARM].write(CLOSE_DOOR[!CORRECT_ARM]);
  doors[!CORRECT_ARM+2].write(CLOSE_DOOR[!CORRECT_ARM+2]);
  
  //prime correct first poke
  digitalWrite(SOLENOID_PINS[CORRECT_ARM],OPEN_SOLENOID);
  delay(REW_VOL * MS_PER_UL[CORRECT_ARM]);
  digitalWrite(SOLENOID_PINS[CORRECT_ARM],CLOSE_SOLENOID);

  //initial TTL
  pinMode(TTL_PINS,OUTPUT);
  //digitalWrite(TTL_PINS,START_TTL);

  //display column names for output
  char buffer[100];
  sprintf(buffer, "Trial,Time,Trajectory,Initiated,Success?,Per_Correct,TL->TR,TL->BR,BL->BR,BL->TR");
  Serial.println(buffer);

  //end TTL
  //digitalWrite(TTL_PINS,END_TTL);
  delay(50); //delay so priming doesn't trigger poke
}

void loop() {
  char buffer[100];
  
  //when trial initiated by poking at open door left port
  if (digitalRead(IR_PINS[CORRECT_ARM])==HIGH && TRIAL_INITIATED==0){
    //output TTL pulse
    digitalWrite(TTL_PINS,START_TTL);

    //print trial time & number to screen
    TRIAL_INITIATED=1;
    sprintf(buffer, "%d,%lu,%d,%d,%d,%d,%d,%d,%d,%d",TRIAL,millis(), \
			CORRECT_ARM,TRIAL_INITIATED,0,0,0,0,0,0);
    Serial.println(buffer);

    // deliver reward
    digitalWrite(SOLENOID_PINS[CORRECT_ARM],OPEN_SOLENOID);
    delay(REW_VOL * MS_PER_UL[CORRECT_ARM]);
    digitalWrite(SOLENOID_PINS[CORRECT_ARM],CLOSE_SOLENOID);

    // open both right doors
    doors[CORRECT_ARM+2].write(OPEN_DOOR[CORRECT_ARM+2]);
    doors[!CORRECT_ARM+2].write(OPEN_DOOR[!CORRECT_ARM+2]);

    // end TTL
    digitalWrite(TTL_PINS,END_TTL);
  }
  
  //when mouse pokes at right side port after trial initiated
  if ((digitalRead(IR_PINS[CORRECT_ARM+2])==HIGH 
			|| digitalRead(IR_PINS[!CORRECT_ARM+2])==HIGH) && TRIAL_INITIATED==1){
    //output TTL pulse
    digitalWrite(TTL_PINS,START_TTL);
    TRIAL_INITIATED=0;

    //if success
    if (digitalRead(IR_PINS[CORRECT_ARM+2])==HIGH){
      //print trial time & number to screen
	    PER_CORRECT = (PER_CORRECT*(TRIAL-1)+1)/TRIAL;
	    TRIAL_TYPE_COUNT[CORRECT_ARM*2]++;
      sprintf(buffer, "%d,%lu,%d,%d,%d,%d,%d,%d,%d,%d",TRIAL,millis(), \
				CORRECT_ARM,TRIAL_INITIATED,1,int(PER_CORRECT*100.0),TRIAL_TYPE_COUNT[0], \
				TRIAL_TYPE_COUNT[1],TRIAL_TYPE_COUNT[2],TRIAL_TYPE_COUNT[3]);

      // deliver reward
      digitalWrite(SOLENOID_PINS[CORRECT_ARM+2],OPEN_SOLENOID);
      delay(REW_VOL * MS_PER_UL[CORRECT_ARM+2]);
      digitalWrite(SOLENOID_PINS[CORRECT_ARM+2],CLOSE_SOLENOID);
	  
	  //block entry to other right arm
	  doors[!CORRECT_ARM+2].write(CLOSE_DOOR[!CORRECT_ARM+2]);
	  
    } else { //if failure
      //print trial time & number to screen
	    PER_CORRECT = (PER_CORRECT*(TRIAL-1))/TRIAL;
	    TRIAL_TYPE_COUNT[CORRECT_ARM*2+1]++;
      sprintf(buffer, "%d,%lu,%d,%d,%d,%d,%d,%d,%d,%d",TRIAL,millis(), \
				CORRECT_ARM,TRIAL_INITIATED,0,int(PER_CORRECT*100.0),TRIAL_TYPE_COUNT[0], \
				TRIAL_TYPE_COUNT[1],TRIAL_TYPE_COUNT[2],TRIAL_TYPE_COUNT[3]);
	  //block entry to other right arm
	  doors[CORRECT_ARM+2].write(CLOSE_DOOR[CORRECT_ARM+2]);
    }

    Serial.println(buffer);
    
    //close currently open door
    doors[CORRECT_ARM].write(CLOSE_DOOR[CORRECT_ARM]);
    delay(500);

    //randomly open top or bottom left door (correct arm)
    //randomSeed(analogRead(1)); //randomize the random generator
    //CORRECT_ARM = random(2);

    //open bottom or top trajectory, alternating every 10 trials
    if (TRIAL%10 == 0) {
      CORRECT_ARM = !CORRECT_ARM;
    }
    doors[CORRECT_ARM].write(OPEN_DOOR[CORRECT_ARM]);
    
    // end TTL
    digitalWrite(TTL_PINS,END_TTL);

    TRIAL++;
  }
}

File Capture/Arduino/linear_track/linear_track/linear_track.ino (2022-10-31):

/*
 * Linear track
 * If the mouse pokes at a poke that wasn't the last poke it poked at,
 * send a TTL pulse, write to Serial, and open the solenoid
 */

// Input & output pins
const int n_pokes = 2;
//order: left, right
const int IR_PINS[n_pokes] = {2,3};
const int SOLENOID_PINS[n_pokes] = {8,9};
const int TTL_PINS = A0;

// State variables
int LAST_PORT = -1; //-1 to start, 0 for left, 1 for right
int TRIAL = 1;

// Other constants
const int REW_VOL = 10; //reward, in uL
const int MS_PER_UL[n_pokes] = {20,12}; //microseconds to release 1uL of soy milk //7,8
const int OPEN_SOLENOID = 1;
const int CLOSE_SOLENOID = 0;
const int START_TTL = 1;
const int END_TTL = 0;

void setup() {
  // initialize the data stream
  Serial.begin(9600); //or 115200

  // set pin modes as input or output
  for (int poke=0; poke<n_pokes; poke++){
    pinMode(IR_PINS[poke],INPUT);
    pinMode(SOLENOID_PINS[poke],OUTPUT);

    //prime the pokes
    digitalWrite(SOLENOID_PINS[poke],OPEN_SOLENOID);
    delay(REW_VOL * MS_PER_UL[poke]);
    digitalWrite(SOLENOID_PINS[poke],CLOSE_SOLENOID);
  }

  //initial TTL
  pinMode(TTL_PINS,OUTPUT);
  //digitalWrite(TTL_PINS,START_TTL);

  //display column names for output
  char buffer[50];
  sprintf(buffer, "Trial,Time");
  Serial.println(buffer);

  //end TTL
  //digitalWrite(TTL_PINS,END_TTL);
  delay(50);
}

void loop() {
  for (int poke=0; poke<n_pokes; poke++){
    //if poke detected and it's a different port
    if (digitalRead(IR_PINS[poke])==HIGH && poke!=LAST_PORT){

      //output TTL pulse
      digitalWrite(TTL_PINS,START_TTL);

      //print trial time & number to screen
      char buffer[50];
      sprintf(buffer, "%d,%lu",TRIAL,millis());
      Serial.println(buffer);

      // open & close solenoid
      digitalWrite(SOLENOID_PINS[poke],OPEN_SOLENOID);
      delay(REW_VOL * MS_PER_UL[poke]);
      digitalWrite(SOLENOID_PINS[poke],CLOSE_SOLENOID);

      // end TTL
      digitalWrite(TTL_PINS,END_TTL);

      // advance values for next trial
      TRIAL++;
      LAST_PORT = poke;
    }
  }
}

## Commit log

2022-10-31 Initial commit from private repo
    [Camera_mount.f3d, Kreitzer_Lab_Electronics_Mount_v0.f3d, Kreitzer_Lab_Face_Mount_v0.f3d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]
2022-10-31 re-organizing & renaming Arduino files
2023-05-30 Migrating parts lists from GDrive to Github
    [Freely Moving Recording Rig Build.xlsx, Mako G Camera Design.xlsx, Neuropixels Acquisition System Parts.xlsx]
2023-08-15 Adding camera build for Blackfly
    [Camera Parts.xlsx, Mako G Camera Design.xlsx]
2023-11-28 Adding new camera instructions and new tubing
    [Freely Moving Recording Rig Build.xlsx]
2023-12-04 adding FLIR camera
2023-12-04 fix camera window sizing
